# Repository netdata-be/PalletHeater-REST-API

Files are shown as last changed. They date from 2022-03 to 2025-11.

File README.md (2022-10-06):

# REST API towards Micronova Stoves

The captive portal has a menu item containing the API documentation

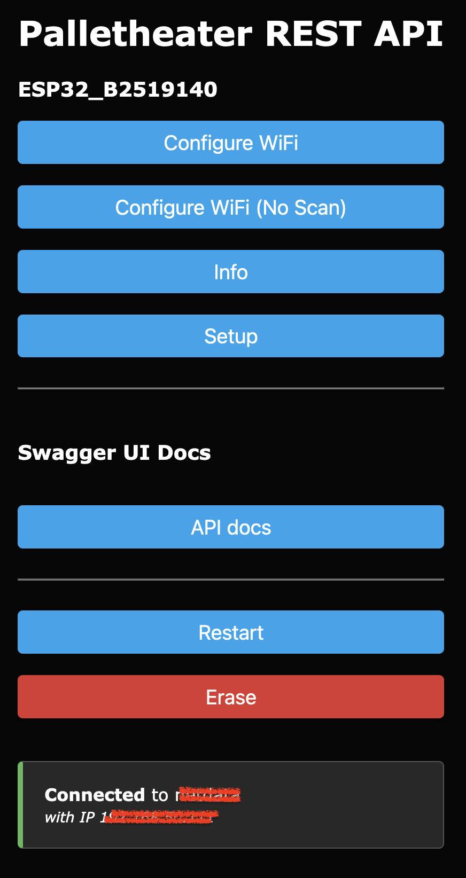
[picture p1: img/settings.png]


# Hardware

I'm using a ESP32 dev board on a custom PCB:

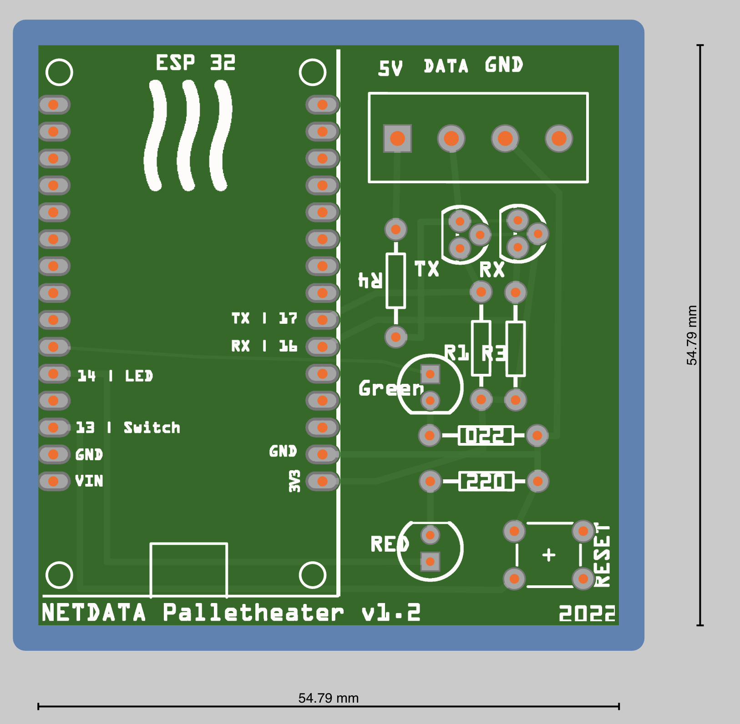
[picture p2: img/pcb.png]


It's using N-Channel MOSFETs to convert the 3.3v TTL towards the 5V TTL the stove understands.
Micronova uses RS232 but TX and RX are coupled together.

This means whathever the ESP is transmittig is also received.
In software we remove the same bits from the received bits in order to have what we need.

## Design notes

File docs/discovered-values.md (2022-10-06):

# Discovered Values

My stove is a Piazzetta 220 M

RAM (0x00)

| ADDR (HEX) | ADDR (DEC) | Formula | Unit | Description | Example or default value | Range |
|---|---|---|---|---|---|---|
| 0x01 | 1 | x/2 | °C | Ambient temperature | 40 (== 20) | |
| 0x04 | 4 | x | Bool | Hot enough for fan? | | |
| 0x0B | 11 | | | Unknown, 0 if off ~ 100 if on | | |
| 0x0D | 13 | x/10 | rpm | Feed rate ??? | | |
| 0x11 | 17 | x | | Countdown counter 20 -> 0 / sec | | |
| 0x13 | 19 | | | Countdown Counter ? 120 -> 0 | | |
| 0x14 | 20 | | | Unknown Boolean value | | | 
| 0x15 | 21 | | | Unknwon value | | |
| 0x18 | 24 | x | id | Parameter on the RC - See lookup table | | |
| 0x19 | 25 | | | Unknown Boolean value /Last changed value?  | | |
| 0x1A | 26 | | | Menu on the RC - See lookup table | | |
| 0x21 | 33 | x | state  | Stove State | 0 | |
| 0x22 | 34 | | | Unknown Boolean value | | |
| 0x23 | 35 | | | Countdown Counter 8 -> 0 | | |
| 0x24 | 36 | | | Countdown last button pressed on remote | 0 | 7 - 0  |
| 0x2E | 46 | | Sec | Countdown since last contact Remote Control | | 0 - 240  |
| 0x30 | 48 | x | Sec | Time till error code? becomse active | 7 | |
| 0x31 | 49 | x | sec | Seconds countdown | | 0 -  59  |
| 0x32 | 50 | x | Min | Countdown when to start brazer cleaning | 45 |  45 - 0  | 
| 0x33 | 51 | bitmask | error  | Errorcode in a bitmask? 32 = E1 ? | 32 | |
| 0x34 | 52 | x | amount | Flame power | | |
| 0x37 | 55 | (x+25)*10 | rpm | smoke fan RPM | 130 (== 1550 ) | |
| 0x3E | 62 | x | °C | Fumesmoke temperature | 105 | |
| 0x44 | 68 | x/2 | °C | Stove room temp ?? | | |
| 0x48 | 72 | (x+25)*10 | rpm | smoke fan RPM | 130 (== 1550 ) | |
| 0x4B | 75 | x | | Counter | | 0 - 254  |
| 0x4C | 76 | | | Flips between 0 and 255 | | |
| 0x4D | 77 | x | | Flip flop 0 / 1 | | 0 - 1  |
| 0x4F | 79 | | | Random ??? | | |
| 0x50 | 80 | x | Min | Time remaining pallets when low | 0 | |
| 0x55 | 85 | | | Looks random | | |
| 0x56 | 86 | | | Looks random | | |
| 0x57 | 87 | | | Random? Jumps every second | | |
| 0x58 | 88 | | | Looks random | | |
| 0x59 | 89 | | | Looks random | | |
| 0x5A | 90 | | | Looks random | | |
| 0x5B | 91 | | | Looks random | | |
| 0x68 | 104 | | | Looks random | | |
| 0x6B | 107 | | Sec | Countdown since last contact Remote Control | | 0 - 240  |
| 0x6D | 109 | x | Sec | Time till error code becomse active | 20 | 0 -  20  |
| 0x79 | 121 | | | Unknown Boolean value | | |
| 0x7A | 122 | x | Sec | Current time (sec) | 1 | 0 -  59  |
| 0x7B | 123 | x | id | Day of week 1=mon / 7=sun | 1 | 1 - 7  |
| 0x7C | 124 | x | Hour | Current time (hour) | 8 | 0 -  23  |
| 0x7D | 125 | x | Min | Current time (min) | 12 | 0 -  59  |
| 0x7E | 126 | x | day | Current Day | 28 | 1 -  31  |
| 0x7F | 127 | x | month  | Current Month | 1 | 1 -  12  |
| 0x80 | 128 | x | year | Current year | 22 | 0 -  99  |
| 0x81 | 129 | | | Counter up | | |
| 0x82 | 130 | | | Unknown counts up really slow ? | | |
| 0x89 | 137 | x | Min | Countdown till low pallet alerm starts | 20 |  20 - 0  |
| 0x8F | 143 | x/2 | °C | Remote control temp | | |
| 0x96 | 150 | | | Unkown 84 - 89 | | |
| 0xAB | 171 | | | Looks random | | |
| 0xAF | 175 | | | Unknown 50 / 51 | | |
| 0xC2 | 194 | | | Looks random (0 - 2 - 6 - 7 ) | | |
| 0xC4 | 196 | | | Looks random | | |
| 0xC6 | 198 | x | | Counter 0-255 fast | | 0 - 255  |
| 0xD0 | 208 | x/2 | °C | Stove room temp ?? | | |
| 0xD2 | 210 | | | Unknown 58 / 57 | | |
| 0XD3 | 211 | x | Bool | Room fan is running | | |
| 0xDF | 223 | x/10 | rpm | Feed rate ??? | | |

Low pallets changes ( To check when pallets are low again)

0x97 (151) =   0 =>  3  ?? |  0 == No Pallets /  3 == All normal => Verified, looks correct
0xC7 (199) =   2 =>  0  ?? |  2 == No Pallets /  0 == All normal?
0xBB (187) =   0 => 30     |  0 == No Pallets / 30 == All Normal?
0xA4 (164) =   5 =>  0     |  5 == No Pallets /  0 == All normal  ======= !!!!
0x9E (158) =  76 => 77     | 76 == No pallets / 77 == All normal 

EEPROM (0x20)

| ADDR (HEX) | ADDR (DEC) | Formula | Unit | Description | Example or default value | Range |
|---|---|---|---|---|---|---|
| 0x02 | | x | Min | Interval between braizer cleanings | 45 | |
| 0x04 | 4 | x/10 | kg/h | Pellets on ignition | 27 == 2,7 | |
| 0x05 | 5 | x/10 | kg/h | Pellets on level 1 | 30 == 3 | |
| 0x06 | 6 | x/10 | kg/h | Pellets on level 2 | 46 == 4,6 | | 
| 0x07 | 7 | x/10 | kg/h | Pellets on level 3 | 62 == 6,2 | | 
| 0x08 | 8 | x/10 | kg/h | Pellets on level 4 | 78 == 7,8 | | 
| 0x09 | 9 | x/10 | kg/h | Pellets on level 5 | 78 == 7,8 | | 
| 0x48 | 72 | x | bool | Ext Thermostat Modulate = 0 / Stop = 1 | 0 | 0 - 1 |
| 0x49 | 73 | x | bool | Ext Thermostat N.O. = 0 / N.C. = 1 | 0 | 0 - 1 |
| 0x4B | 75 | x | bool | Beep is enabled | 1 | 0 - 1 |
| 0x4F | 79 | x | id | Language remote, see lookup table | 1 | 1 - 8 |
| 0x7D | 125 | x | °C | Setpoint Room Temperature | 23 | |
| 0x7F | 127 | x | amount | Flame power level | | 1 - 4 |
| 0x81 | 129 | x | speed  | Room fan speed | 0 | 0 - 3 |
| 0xC0 | 192 | x | id | Combustion Quality, see lookup | 76 | |
| 0xC6 | 198 | x | bool | Low pallets monitoring | 1 | 0 - 1 |
| 0xC4 | 196 | x | bool | Pallet contact N.O. = 0 / N.C. = 1 | 0 | 0 - 1 |
| 0xE0 | 224 | x | error  | Memory Error - Position 1 - See table  | | |
| 0xE1 | 225 | x | error  | Memory Error - Position 2 - See table  | | |
| 0xE2 | 226 | x | error  | Memory Error - Position 3 - See table  | | |
| 0xE3 | 227 | x | error  | Memory Error - Position 4 - See table  | | |
| 0xE4 | 228 | x | error  | Memory Error - Position 5 - See table  | | |
| 0xE7 | 231 | x | hours  | Working hours ??? | | |
| 0xEA | 234 | x | hours  | Working hours ??? | | |
| 0xEC | 236 | x | hours  | Working hours ??? | | |
| 0xEE | 238 | x | amount | Amount of starts | 1 | ??? |
| 0xFA | 250 | | | Unknown | | |

# menu Item on remote  (RAM 0x1A)

Not fully completed yet

| ID  | Selected Item |
|-----|---|
| 0 | Main screen |
| 1 | Multifuoco |
| 2 | Chrono |
| 3 | Language |
| 5 | Clock |
| 7 | Multicomfort |
| 8 | Multi Comfort Plus |
| 9 | Enegery Saving |
| 11  | Beep |
| 12  | Display |
| 13  | Installer |
| 39  | -- FILL AUGER |
| 40  | -- Pallet reserve |
| 41  | -- Pallet contact |
| 42  | -- External Thermo |
| 43  | -- Memory |
| 51  | ---- Total Hours |
| 52  | ---- Interval hours |
| 53  | ---- Amount of starts |
| 54  | ---- Error Memory |
| 44  | -- Pallet quality |
| 46  | -- Setting wireless |
| 47  | -- Link wireless |
| 49  | -- Parameters |
| 14  | State Stove |
| 15  | exit |

# Selected in menu (RAM 0x18)

| ID  | Selected Item |
|-----|---|
| 0 | nothing |
|  71 | Multi Comfort |
|  76 | Beep |
|  79 | Display settings |
|  80 | Language |
| 123 | State Stove |
| 130 | MultiFuoco |
| 145 | Energy Saving - Stop  |
| 146 | Energy Saving - Start |
| 200 | Multi Comfort Plus |
| 248 | Day of week |
| 249 | Hour |
| 250 | min | 
| 251 | Day |
| 252 | Month |
| 253 | year |

# Error codes

| Val | Binary | Error Code  | Description |
|---|---|---|---|
| 0 | 00000000 | - | No Error |
| 1 | 00000001 | E8 | Fume sensor error |
| 2 | 00000010 | E4 | Fume temperature to high |
| 4 | 00000100 | E9 | Ignition temperature not reached within limit |
| 8 | 00001000 | E7 | Fume temperatuer to low |
|  16 | 00010000 | E3 | Temperature inside stove to high |
|  32 | 00100000 | E1 | Pallet loading door is open for to long or air pressure inside stove is wrong |
|  64 | 01000000 | E2 | Pressure sensor error during ignition |
| 128 | 10000000 | E6 | Auger error - To much pallets are dispatched |
| 129 | 10000001 | E12 | Fume fan error |
| 130 | 10000010 | E11 | Unknown error - Not described in manual |
| 132 | 10000100 | E19 | External contact N.PEL / Pallet is active |
| 136 | 10001000 | E13 | Unknown error - Not described in manual |
| 255 | 11111111 | Power Error | Display shows power error 

Coundn't reverse the following error codes :
- E10
- E14

# Language

| Val | Language |
|-----|---|
| 1 | ENG |
| 2 | FRA |
| 3 | DEU |
| 4 | NLD |
| 5 | POR |
| 6 | SPA |
| 7 | HRV |
| 8 | DAN |

# Combustion Quality

| Val | Setting |
|-----|---|
| 76  | +G |
|  2  | -3 |
|  3  | -2 |
|  4  | -1 |
|  5  |  0 |
|  6  | +1 |
|  7  | +2 |
|  8  | +3 |

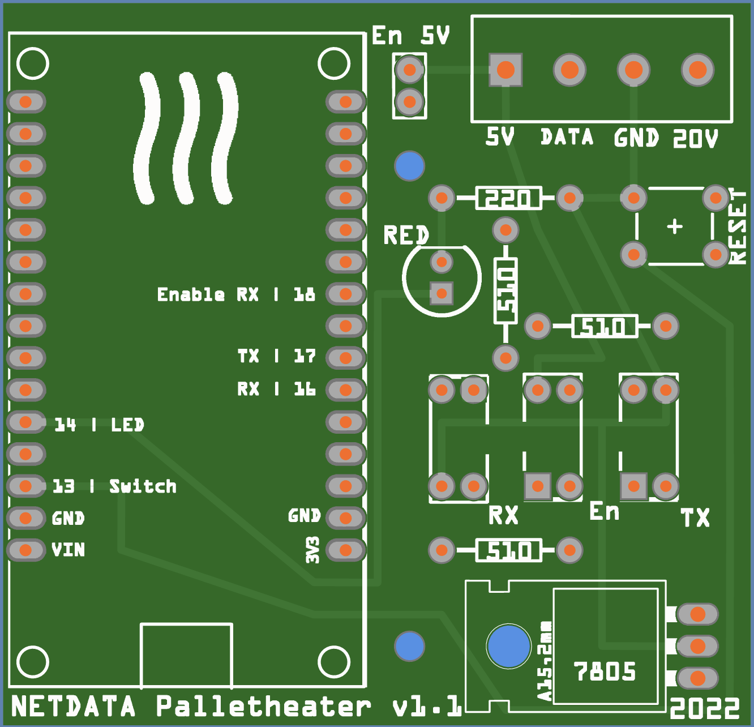
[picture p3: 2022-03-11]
Fritzing/pcb-aisler.png

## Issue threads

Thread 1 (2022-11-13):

Wiring diagram to pellet stove

vyruz1986, 2022-11-13:
Hi there, thanks for publishing this project!

I'm looking for a way to make my 'La Nordica Extraflame - Emma plus' pellet stove a little smarter by being able to control it from [home assistant](https://www.home-assistant.io/). Besides this repository, I also found [this](https://github.com/philibertc/micronova_controller) and [this](https://github.com/edenhaus/esphome-extraflame) repositories.

Unfortunately, both of the other repositories don't work for me (I created an issue in philibertc's repo [here](https://github.com/philibertc/micronova_controller/issues/47)), so I would like to give this solution a try.

However I'm struggling to figure out how the schematics of this solution work. I don't have Fritzing, and apparently, it's not free to download anymore (I think it used to be, long time ago) so would rather not pay for it without knowing if it's even going to work for my pellet stove.
So it would be great if you could post an image export of the schematic.
Also, let me know if you would be open for me to create a PR with the schematic and board re-done in KiCad, that way you would have an open-source solution for the hardware as well that would be accessible to everyone, not just paying Fritzing users.  If you're open to it, I would consider creating a PR.

Besides that, I'm still struggling to find the correct pinout of my pellet stove, could you describe which stove you have, what the serial port looks like and how you identified the 5V, Data and GND pins mentioned on your PCB in the readme?

Thanks!

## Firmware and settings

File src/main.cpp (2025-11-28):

#include <ArduinoJson.h>
#include <ArduinoOTA.h>
#include <ota.h>
#include <constants.h>
#include <setupWifi.h>
#include <FS.h>
#include <SPIFFS.h>
#include <WiFiManager.h>
#include <WiFiUdp.h>
#include <metrics.h>

#include <helperFunctions.h>
#include "Stove.h"

#define FORMAT_SPIFFS_IF_FAILED true


bool getNTPtime(int sec)
{

    {
        uint32_t start = millis();
        do
        {
            time(&now);
            localtime_r(&now, &timeinfo);
            Serial.print(".");
            delay(10);
        } while (((millis() - start) <= (1000 * sec)) && (timeinfo.tm_year < (2016 - 1900)));
        if (timeinfo.tm_year <= (2016 - 1900))
            return false; // the NTP call was not successful
        Serial.print("now ");
        Serial.println(now);
        char time_output[30];
        strftime(time_output, 30, "%a  %d-%m-%y %T", localtime(&now));
        Serial.println(time_output);
        Serial.println();
    }
    return true;
}



void getAmbTemp() // Get room temperature
{
    ambTemp = stove.read(ram, ambTempAddr);
    if (ambTemp >= 0)
    {
        ambTemp = (float)ambTemp / 2;
    }
    else
    {
        log_e("Failed to get value");
    }
    Serial.print("T. amb. ");
    Serial.println(ambTemp);
}

int getFumeFanRPM()
{
    int rpm = stove.read(ram, 0x37);
    if (rpm > 0)
    {
        rpm = (rpm + 25) * 10;
    }
    return rpm;
}

int getRemoteControlLastSeen()
{
    int ttl = stove.read(ram, 0x2e);
    if (ttl > 0)
    {
        ttl = 240 - ttl;
    }
    else
    {
        ttl = -1;
    }
    return ttl;
}

void getAmbTempStove() // Get room temperature from stove sensor
{
    ambTempStove = stove.read(ram, 0x44);
    if (ambTempStove >= 0)
    {
        ambTempStove = (float)ambTempStove / 2;
    }
    else
    {
        log_e("Failed to get value");
    }
    Serial.print("T. amb. stove : ");
    Serial.println(ambTempStove);
}

void getAmbTempRemoteControl() // Get room temperature from stove sensor
{
    ambTempRemoteControl = stove.read(ram, 0x8f);
    if (ambTempRemoteControl >= 0)
    {
        ambTempRemoteControl = (float)ambTempRemoteControl / 2;
    }
    else
    {
        log_e("Failed to get value");
    }
    Serial.print("T. amb. remote control : ");
    Serial.println(ambTempRemoteControl);
}

int numberOfStarts()
{
    return ( stove.read(eeprom, 0xef) << 8 ) + stove.read(eeprom, 0xee);
}

bool stoveBeepIsEnabled() // Get room temperature
{
    ambTemp = stove.read(eeprom, 0x4b);
    if (ambTemp == 0)
    {
        return false;
    }
    else
    {
        return true;
    }
}

int arePalletsLow()
{
    int val = stove.read(ram, 0xa4);
    if (val == 5)
    {
        val = stove.read(ram, 0x89);
        if (val <= 1) {
            return 1;
        }
        else {
            return 0;
        }
    }
    else
    {
        return 0;
    }
}

void getTempSetpoint()
{
    setPointTemp = (float)stove.read(eeprom, TempSetpointAddr);
    Serial.print("T. setpoint. ");
    Serial.println(setPointTemp);
}

void getFumeTemp() // Get flue gas temperature
{
    fumesTemp = stove.read(ram, fumesTempAddr);
    Serial.printf("T. fumes %d\n", fumesTemp);
}

void writeDatepartToStove(char format[3], byte address)
{
    char time_output[30];
    int number;
    int mostSigDigit;
    int leastSigDigit;
    byte value;

    strftime(time_output, 30, format, localtime(&now));
    number = atoi(time_output);
    mostSigDigit = number / 10;
    leastSigDigit = number % 10;

    value = mostSigDigit * 0x10 + leastSigDigit;

    stove.write(eeprom, address, value);
}

void setStoveDateTime()
{
    getNTPtime(2);
    writeDatepartToStove("%d", 0xfb); // Write NTP date part: Day
    writeDatepartToStove("%m", 0xfc); // Write NTP date part: Month
    writeDatepartToStove("%y", 0xfd); // Write NTP date part: Year
    writeDatepartToStove("%H", 0xf9); // Write NTP date part: Hour
    writeDatepartToStove("%M", 0xfa); // Write NTP date part: Minute
    writeDatepartToStove("%W", 0xf8); // Write NTP date part: Day of Week
}

void getRoomFanSpeed()
{
    roomFanSpeed = stove.read(eeprom, 0x81);
    Serial.printf("Fan speed: %d\n", roomFanSpeed);
}

void getFlamePower() // Get the flame power (0, 1, 2, 3, 4, 5)
{
    flamePower = stove.read(eeprom, 0x7f);
}

void getStates() // Calls all the get…() functions
{
    getStoveState();
    getAmbTemp();
    getAmbTempStove();
    getAmbTempRemoteControl();
    getFumeTemp();
    getFlamePower();
    getRoomFanSpeed();
    getTempSetpoint();
}

void fullReset()
{
    onboardLED.off();
    onboardLED.flash(20, 50, 50, 50, 50);
    Serial.println("Resetting…");
    wm.resetSettings();
    SPIFFS.format();
    Serial.println("[DONE]");
    onboardLED.flash();
    ESP.restart();
}

void buttonPressed()
{
    led.toggle();
    Serial.println("Button has been pressed");
}

bool setDisplay(int menu)
{
    stove.write(ram, 0x1a, menu);
    return true;
}

bool setRoomFanSpeed(int speed)
{
    if ((speed >= 0) & (speed <= 3))
    {
        if (stove.write(eeprom, 0x81, speed) ) {
            return stove.write(ram, 0x19, speed);
        } else {
            return false;
        }
    }
    else
    {
        log_e("Speed not in range, it should be between 0-3\n");
        return false;
    }
}

void setCombustionQuality(int speed)
{
    stove.write(eeprom, 0xc0, speed);
}

int readErrorMemory(int pos)
{
    switch (pos)
    {
    case 0 ... 4:
        pos = 0xe0 + pos;
        return stove.read(eeprom, byte(pos));
        break;
    }
    return -1;
}

int getErrorMemory(int pos)
{
    int error = -1;
    switch (pos)
    {
    case 0 ... 4:
        pos = 0xe0 + pos;
        error = stove.read(eeprom, byte(pos));
        break;
    }
    return error;
}

bool setFlamePower(int power)
{
    if ((power >= 1) & (power <= 4))
    {
        return stove.write(eeprom, 0x7f, power);
    }
    else
    {
        log_e("Flamepower not in range, it should be between 0-3\n");
        return false;
    }
}

void setError(int pos, int error)
{
    int address = 0xe0 + pos;
    stove.write(eeprom, address, error);
}

void handleRouteCQ()
{
    StaticJsonDocument<350> json;
    json.clear();

    for (uint8_t i = 0; i < wm.server->args(); i++)
    {
        if (wm.server->argName(i) == "s")
        {
            int speed = wm.server->arg(i).toInt();
            setCombustionQuality(speed);
        }
    }

    json["action"] = "ok";

    serializeJson(json, buffer);
    wm.server->send(200, "application/json", buffer);
}

void handleRouteDisplay()
{
    StaticJsonDocument<350> json;
    json.clear();

    for (uint8_t i = 0; i < wm.server->args(); i++)
    {
        if (wm.server->argName(i) == "menu")
        {
            int menu = wm.server->arg(i).toInt();
            setDisplay(menu);
        }
    }

    json["action"] = "ok";

    serializeJson(json, buffer);
    wm.server->send(200, "application/json", buffer);
}

void getStoveDateTime()
{
    int cur_min = stove.read(ram, 0x7d);
    int cur_hour = stove.read(ram, 0x7c);
    int cur_sec = stove.read(ram, 0x7a);
    int cur_day = stove.read(ram, 0x7e);
    int cur_month = stove.read(ram, 0x7f);
    int cur_year = stove.read(ram, 0x80);

    sprintf(buffer, "20%i-%02d-%02d %02d:%02d:%02d", cur_year, cur_month, cur_day, cur_hour, cur_min, cur_sec);

    strptime(buffer, "%Y-%m-%d %H:%M:%S", &tm);
    // Take the current NTP based DST setting in order to interprete the stove it's Time
    // The stove does not support DST so a time change is required
    tm.tm_isdst = timeinfo.tm_isdst;
    stoveTime = mktime(&tm);
}

void handleRouteSwaggerUI() { 
    wm.server->send(200, "text/html", swaggerUI);
}

void handleRouteSwaggerJSON() { 
    wm.server->send(200, "application/json", swaggerJSON);
}

void handleRouteTime()
{
    StaticJsonDocument<350> json;
    char time_output[30];
    int http_code;
    http_code=200;

    json.clear();

    if (wm.server->method() == HTTP_PATCH) 
    {
        setStoveDateTime();
        json["result"] = "success Synced NTP time to stove";
        delay(100);
    }
    
    if (wm.server->method() == HTTP_GET || wm.server->method() == HTTP_PATCH )
    {
        JsonObject time = json.createNestedObject("time");
        getStoveDateTime();
        strftime(time_output, 30, "%F %T", localtime(&stoveTime));
        time["stove"] = time_output;

        strftime(time_output, 30, "%F %T", localtime(&now));
        time["ntp"] = time_output;

        time["delta"] = now - stoveTime;
    } else
    {
        http_code=405;
    }


    serializeJson(json, buffer);
    wm.server->send(http_code, "application/json", buffer);
}

void handleRouteFanspeed()
{
    StaticJsonDocument<350> json;
    int http_code;
    http_code=200;
    json.clear();

    if (wm.server->method() == HTTP_POST)
    {
        for (uint8_t i = 0; i < wm.server->args(); i++)
        {
            if (wm.server->argName(i) == "speed")
            {
                if (  wm.server->arg(i) == "0" ||  wm.server->arg(i) == "1" ||  wm.server->arg(i) == "2" ||  wm.server->arg(i) == "3") 
                {
                    int speed = wm.server->arg(i).toInt();
                    if ( setRoomFanSpeed(speed) )
                    {
                        json["result"] = "success";
                    } else 
                    {
                        json["result"] = "Failed - RS2232 error...";
                        http_code=500;
                    }
                    delay(50);
                } else 
                {
                    json["result"] = "failed - Speed is out of range: Should be between 0 and 3";
                    http_code=400;
                }
            }
        }
    }
    
    if (wm.server->method() == HTTP_GET || wm.server->method() == HTTP_POST)
    {
        getRoomFanSpeed();
        json["speed"] = roomFanSpeed;
    } else {
        wm.server->send(405);
    }

    serializeJson(json, buffer);
    wm.server->send(http_code, "application/json", buffer);
}

void handleRouteErrors()
{
    StaticJsonDocument<450> json;
    json.clear();

    if (wm.server->method() == HTTP_POST)
    {
        for (uint8_t i = 0; i < wm.server->args(); i++)
        {
            if (wm.server->argName(i) == "MemoryPos_1")
            {
                int error = wm.server->arg(i).toInt();
                setError(0, error);
                json["action"] = "MemoryPos_1 set";
                delay(50);
            }
            if (wm.server->argName(i) == "MemoryPos_2")
            {
                int error = wm.server->arg(i).toInt();
                setError(1, error);
                json["action"] = "MemoryPos_2 set";
                delay(50);
            }
            if (wm.server->argName(i) == "MemoryPos_3")
            {
                int error = wm.server->arg(i).toInt();
                setError(2, error);
                json["action"] = "MemoryPos_3 set";
                delay(50);
            }
            if (wm.server->argName(i) == "MemoryPos_4")
            {
                int error = wm.server->arg(i).toInt();
                setError(3, error);
                json["action"] = "MemoryPos_4 set";
                delay(50);
            }
            if (wm.server->argName(i) == "MemoryPos_5")
            {
                int error = wm.server->arg(i).toInt();
                setError(4, error);
                json["action"] = "MemoryPos_5 set";
                delay(50);
            }
        }
    }
    
    if (wm.server->method() == HTTP_GET || wm.server->method() == HTTP_POST)
    {
        JsonObject errorbank1 = json.createNestedObject("MemoryPos_1");
        int error = getErrorMemory(0);
        errorbank1["id"] = error;
        errorbank1["error"] = getErrorCode(error);
        errorbank1["desc"] = getErrorDesc(error);

        JsonObject errorbank2 = json.createNestedObject("MemoryPos_2");
        error = getErrorMemory(1);
        errorbank2["id"] = error;
        errorbank2["error"] = getErrorCode(error);
        errorbank2["desc"] = getErrorDesc(error);

        JsonObject errorbank3 = json.createNestedObject("MemoryPos_3");
        error = getErrorMemory(2);
        errorbank3["id"] = error;
        errorbank3["error"] = getErrorCode(error);
        errorbank3["desc"] = getErrorDesc(error);

        JsonObject errorbank4 = json.createNestedObject("MemoryPos_4");
        error = getErrorMemory(3);
        errorbank4["id"] = error;
        errorbank4["error"] = getErrorCode(error);
        errorbank4["desc"] = getErrorDesc(error);

        JsonObject errorbank5 = json.createNestedObject("MemoryPos_5");
        error = getErrorMemory(4);
        errorbank5["id"] = error;
        errorbank5["error"] = getErrorCode(error);
        errorbank5["desc"] = getErrorDesc(error);
    } else
    {
        wm.server->send(405);
    }

    serializeJson(json, buffer);
    wm.server->send(200, "application/json", buffer);
}

void handleRouteSetError()
{
    StaticJsonDocument<350> json;
    json.clear();

    for (uint8_t i = 0; i < wm.server->args(); i++)
    {
        if (wm.server->argName(i) == "0")
        {
            int error = wm.server->arg(i).toInt();
            setError(0, error);
        }
        if (wm.server->argName(i) == "1")
        {
            int error = wm.server->arg(i).toInt();
            setError(1, error);
        }
        if (wm.server->argName(i) == "2")
        {
            int error = wm.server->arg(i).toInt();
            setError(2, error);
        }
        if (wm.server->argName(i) == "3")
        {
            int error = wm.server->arg(i).toInt();
            setError(3, error);
        }
        if (wm.server->argName(i) == "4")
        {
            int error = wm.server->arg(i).toInt();
            setError(4, error);
        }
    }

    json["action"] = "ok";

    serializeJson(json, buffer);
    wm.server->send(200, "application/json", buffer);
}

void handleRouteHealth()
{
    StaticJsonDocument<350> json;
    json.clear();
    int http_code;
    if (wm.server->method() == HTTP_GET)
    {
        if (stove.read(ram, ambTempAddr)) 
        {
            json["health"] = "Healthy";
            http_code=200;

        } else 
        {
            json["health"] = "Faild to talk to Stove";
            http_code=500;
        }
    } else {
        wm.server->send(405);
    }

    serializeJson(json, buffer);
    wm.server->send(http_code, "application/json", buffer);
}

void handleRouteFlamePower()
{
    StaticJsonDocument<350> json;
    int http_code;
    http_code=200;
    json.clear();


    if (wm.server->method() == HTTP_POST)
    {
        for (uint8_t i = 0; i < wm.server->args(); i++)
        {
            if (wm.server->argName(i) == "power")
            {
                if (  wm.server->arg(i) == "1" ||  wm.server->arg(i) == "2" ||  wm.server->arg(i) == "3" ||  wm.server->arg(i) == "4") 
                {
                    int power = wm.server->arg(i).toInt();
                    if (setFlamePower(power))
                    {
                        json["result"] = "success";
                        http_code=200;
                    } else
                    {
                        json["result"] = "Failed - RS2232 error...";
                        http_code=500;
                    } 
                    delay(50);
                } else 
                {
                    json["result"] = "failed - power is out of range: Should be between 1 and 4";
                    http_code=400;
                }
            }
        }
    }
    
    if (wm.server->method() == HTTP_GET || wm.server->method() == HTTP_POST)
    {
        getFlamePower();
        json["power"] = flamePower;
    } else
    {
        wm.server->send(405);
    }

    serializeJson(json, buffer);
    wm.server->send(http_code, "application/json", buffer);
}

void handleRoutePower()
{
    StaticJsonDocument<350> json;
    json.clear();
    int http_code;
    http_code=200;

    getStoveState();
    

    if (wm.server->method() == HTTP_POST)
    {
        for (uint8_t i = 0; i < wm.server->args(); i++)
        {
            if (wm.server->argName(i) == "state")
            {
                if (  wm.server->arg(i) == "off" ) 
                {
                    String message;
                    switch (stoveState)
                    {
                        case OFF:
                        case ALARM_STATE:
                        case IGNITION_FAILURE:
                        case STANDBY:
                            message = "Stove already off";
                            http_code=202;
                        break;
                        case STARTING:
                        case PALLET_LOADING:
                            if (stove.write(ram, stoveStateAddr, 0))
                            {
                                message = "Powered off sended - 0";
                            }
                            else
                            {
                                message = "FAILED to send Power off - 0";
                                http_code=500;
                            }
                        break;
                        case IGNITION:
                        case WORKING:
                        case ALARM:
                            if (stove.write(ram, stoveStateAddr, 6))
                            {
                                message = "Powered off sended - 6";
                            }
                            else
                            {
                                message = "FAILED to send Power off - 6";
                                http_code=500;
                            }
                        break;
                        case BRAZIER_CLEANING:
                            message = "Stove already shutting down - Brazier cleaning";
                            http_code=202;
                        break;
                        case FINAL_CLEANING:
                            message = "Stove already shutting down - Final cleaning";
                            http_code=202;
                        break;
                        case UNKNOWN:
                            StoveStateStr = "Unkown [RS232 Serial Error]";
                            http_code=500;
                        break;

                    }
                    json["result"] = message;
                } else if (wm.server->arg(i) == "on")
                {
                    String message;
                    if (stoveState == 0)
                    {
                        if (stove.write(ram, stoveStateAddr, 1))
                        {
                            message = "Powered on sended";
                        } 
                        else
                        {
                            message = "FAILED to send Power on";
                            http_code=500;
                        }
                    } 
                    else
                    {
                        message = "Stove already on";
                        Serial.print("Stove already on\n");
                        http_code=202;
                    }
                    json["result"] = message;
                } else 
                {
                    json["result"] = "Unknown state argument";
                    http_code=400;
                }
            }
        }
    }
    delay(50);
    getStoveState();
    json["stoveState"] = stoveState;
    json["state"] = StoveStateStr;
    json["poweredOn"] = StoveIsOn;

    serializeJson(json, buffer);
    wm.server->send(http_code, "application/json", buffer);
}

void setStoveOn()
{
    String message;
    int http_code;
    http_code=200;
    StaticJsonDocument<250> json;
    json.clear();
    getStoveState();
    if (stoveState == 0)
    {
        if (stove.write(ram, stoveStateAddr, 1))
        {
            message = "Powered on sended";
        }
        else
        {
            message = "FAILED to send Power on";
            http_code = 500;
        }
    }
    else
    {
        message = "Stove already on";
        http_code = 202;
        Serial.print("Stove already on\n");
    }

    json["result"] = message;

    delay(50);
    getStoveState();
    JsonObject obj_stove = json.createNestedObject("stoveState");
    obj_stove["stoveState"] = stoveState;
    obj_stove["state"] = StoveStateStr;
    obj_stove["poweredOn"] = StoveIsOn;

    serializeJson(json, buffer);
    getStoveState();
    wm.server->send(http_code, "application/json", buffer);
}
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
void loop()
{
    telnet.loop();
    esp_task_wdt_reset();
    wm.process();
    resetButton.read();
    ArduinoOTA.handle();

    unsigned long currentMillis = millis();
    if (previousMillis > currentMillis)
    {
        previousMillis = 0;
    }
    if (currentMillis - previousMillis >= 10000)
    {
        if (WiFi.status() != WL_CONNECTED)
        {
            onboardLED.off();
            onboardLED.flash();
            Serial.println("Reconnecting to WiFi...");
            WiFi.reconnect();
        }
        if (WiFi.status() == WL_CONNECTED)
        {
            getNTPtime(2);
            onboardLED.on();
        }
        getStates();
        previousMillis = currentMillis;
    }
}

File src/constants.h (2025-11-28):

#ifndef CONSTANTS_H
#define CONSTANTS_H

#include <WiFiManager.h>
#include <WiFiUdp.h>
#include "EasyLed.h"
#include <EasyButton.h>
#include "time.h"
#include "Stove.h"


#ifdef ESP32
#include <FS.h>
#include "ESPTelnet.h" 
#include <SPIFFS.h>
#include "esp_log.h"
#include <esp_task_wdt.h>
#define RESET_PIN 13
#define ENABLE_RX 18
#define ONBOARD_LED 2
#define LED 14
#define WDT_TIMEOUT 5
#endif

const char* ntpServer = "nl.pool.ntp.org";
const char * defaultTimezone = "CET-1CEST,M3.5.0/2,M10.5.0/3";

tm timeinfo;
struct tm tm = {0};
time_t now;
time_t stoveTime;
long unsigned lastNTPtime;
unsigned long lastEntryTime;

WiFiUDP udp;
WiFiClient espClient;
ESPTelnet telnet;
EasyButton resetButton(RESET_PIN);

const char * swaggerUI = "<!DOCTYPE html><html lang=\"en\"> <head> <meta charset=\"UTF-8\"> <title>Swagger UI</title> <link rel=\"stylesheet\" type=\"text/css\" href=\"https://cdnjs.cloudflare.com/ajax/libs/swagger-ui/4.14.2/swagger-ui.css\"/> <link rel=\"stylesheet\" type=\"text/css\" href=\"https://cdnjs.cloudflare.com/ajax/libs/swagger-ui/4.14.2/swagger-ui.css\"/> </head> <body> <div id=\"swagger-ui\"></div><script src=\"https://cdnjs.cloudflare.com/ajax/libs/swagger-ui/4.14.2/swagger-ui-bundle.js\" charset=\"UTF-8\"> </script> <script src=\"https://cdnjs.cloudflare.com/ajax/libs/swagger-ui/4.14.2/swagger-ui-standalone-preset.js\" charset=\"UTF-8\"> </script> <script>window.onload=function(){window.ui=SwaggerUIBundle({url: \"api-specs.json\", dom_id: '#swagger-ui', deepLinking: true, presets: [ SwaggerUIBundle.presets.apis, SwaggerUIStandalonePreset], plugins: [ SwaggerUIBundle.plugins.DownloadUrl], layout: \"StandaloneLayout\"});}; </script> </body></html>";
const char * swaggerJSON = "{\"openapi\":\"3.0.1\",\"info\":{\"title\":\"Palletheater REST API\",\"description\":\"This API runs on a ESP32 an provides using the hardware serial UART2 an HTTP interface towards micronova pallet stoves.\",\"version\":\"0.3\"},\"paths\":{\"\/api\/flame\":{\"get\":{\"tags\":[\"Flame power\"],\"description\":\"Get the current flame power, can be 1 - 2 - 3 - 4\",\"responses\":{\"200\":{\"description\":\"Succesful fetech the current flame power\",\"content\":{\"application\/json\":{\"schema\":{\"type\":\"object\",\"properties\":{\"power\":{\"description\":\"The amount of pallets falling\",\"enum\":[1,2,3,4],\"type\":\"integer\"}}},\"examples\":{\"Power level 1\":{\"value\":\"{\\\"power\\\":1}\"},\"Power level 2\":{\"value\":\"{\\\"power\\\":2}\"},\"Power level 3\":{\"value\":\"{\\\"power\\\":3}\"},\"Power level 4\":{\"value\":\"{\\\"power\\\":4}\"}}}}}}},\"post\":{\"tags\":[\"Flame power\"],\"description\":\"Set the current flame power\",\"parameters\":[{\"name\":\"power\",\"in\":\"query\",\"required\":true,\"schema\":{\"type\":\"integer\",\"enum\":[1,2,3,4]},\"example\":\"1\"}],\"responses\":{\"200\":{\"description\":\"Succesfully set\",\"content\":{\"application\/json\":{\"schema\":{\"type\":\"object\",\"properties\":{\"result\":{\"type\":\"string\"},\"power\":{\"type\":\"integer\"}}},\"examples\":{\"Powerlevel 1\":{\"value\":\"{\\\"result\\\":\\\"success\\\",\\\"power\\\":1}\"},\"Powerlevel 2\":{\"value\":\"{\\\"result\\\":\\\"success\\\",\\\"power\\\":2}\"},\"Powerlevel 3\":{\"value\":\"{\\\"result\\\":\\\"success\\\",\\\"power\\\":3}\"},\"Powerlevel 4\":{\"value\":\"{\\\"result\\\":\\\"success\\\",\\\"power\\\":4}\"}}}}},\"400\":{\"description\":\"Wrong value, this means you have submitted the wrong int to the `power` argument.\",\"content\":{\"application\/json\":{\"schema\":{\"type\":\"object\",\"properties\":{\"result\":{\"type\":\"string\"},\"power\":{\"type\":\"integer\"}}},\"examples\":{\"Failed\":{\"value\":\"{\\\"result\\\":\\\"failed - power is out of range: Should be between 1 and 4\\\",\\\"power\\\":1}\"}}}}},\"500\":{\"description\":\"Can happen when the RS232 communication fails\",\"content\":{\"application\/json\":{\"schema\":{\"type\":\"object\",\"properties\":{\"result\":{\"type\":\"string\"},\"power\":{\"type\":\"integer\"}}},\"examples\":{\"Failed\":{\"value\":\"{\\\"result\\\":\\\"Failed - RS2232 error...\\\",\\\"power\\\":-1}\"}}}}}}}},\"\/api\/time\":{\"get\":{\"tags\":[\"Date and Time\"],\"description\":\"Get the stove it's internal time reference as well as NTP based time\",\"responses\":{\"200\":{\"description\":\"Successful\",\"content\":{\"application\/json\":{\"schema\":{\"type\":\"object\",\"properties\":{\"time\":{\"type\":\"object\",\"properties\":{\"stove\":{\"type\":\"string\"},\"delta\":{\"type\":\"integer\"},\"ntp\":{\"type\":\"string\"}}}}},\"examples\":{\"Example\":{\"value\":\"{\\\"time\\\":{\\\"stove\\\":\\\"2022-10-05 17:50:12\\\",\\\"ntp\\\":\\\"2022-10-05 17:50:38\\\",\\\"delta\\\":26}}\"}}}}}}},\"patch\":{\"tags\":[\"Date and Time\"],\"description\":\"Set the stove time to the NTP timesource\",\"responses\":{\"200\":{\"description\":\"Successfull synced the internal
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

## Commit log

2022-03-11 Adding fritzing
    [micronova.fzz]
2026-03-27 Wrap prints into debug flag for speed
